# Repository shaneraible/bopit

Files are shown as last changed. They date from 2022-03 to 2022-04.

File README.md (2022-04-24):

# Disarm-It!
This project is based off the popular game Bop-It! 
In our version, we have three inputs:
- Scan it!
- Unlock it!
- Password it!

The software folder contains all of the arduino files, the pcb folder has all PCB files and the enclosure folder has all fusion360 files for the enclosure.

To achieve this, we created a PCB and 3D printed enclosure to go with the game. Enclosure design was done in Fusion360 and the PCB was design in Altium. 

# The PCB:
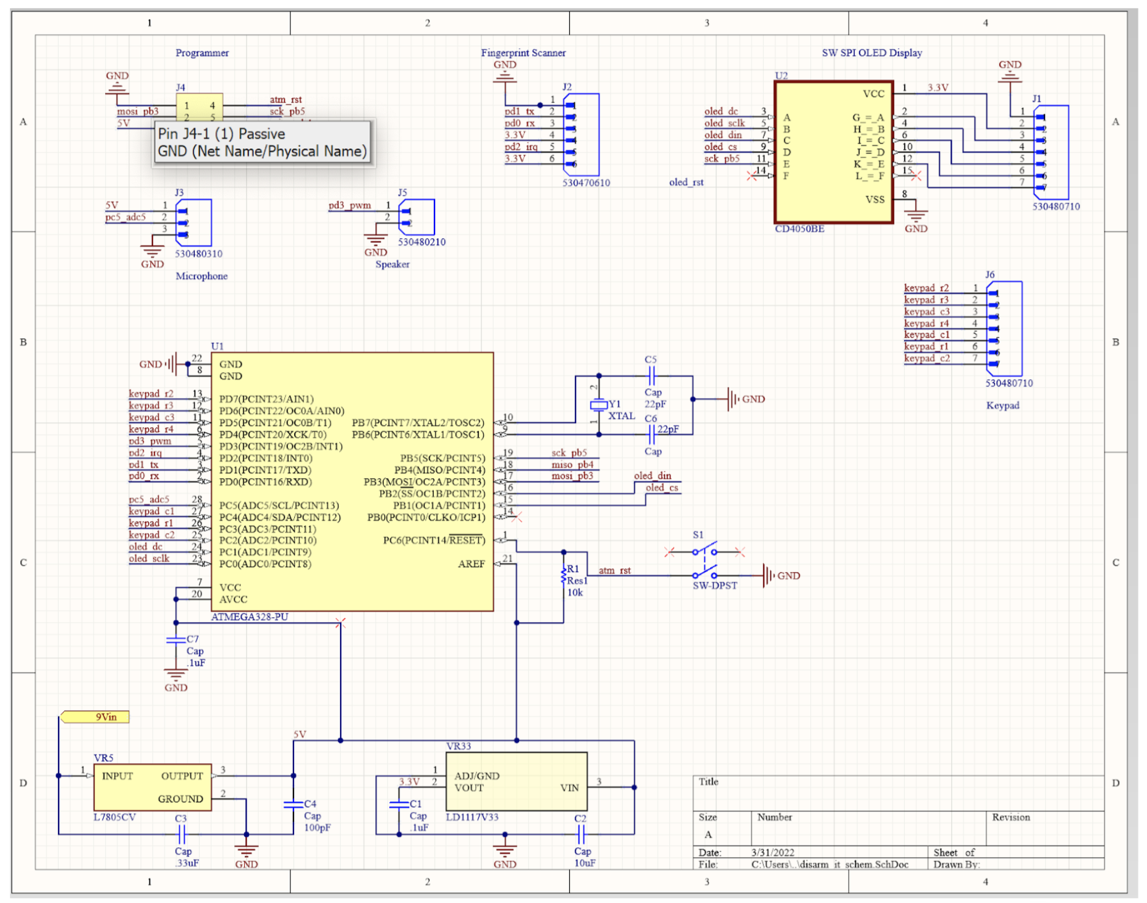
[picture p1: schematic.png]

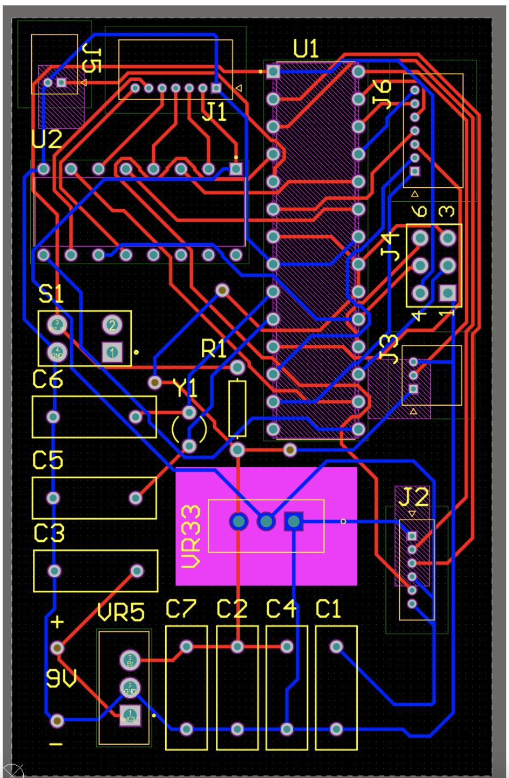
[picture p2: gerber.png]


# The enclosure:
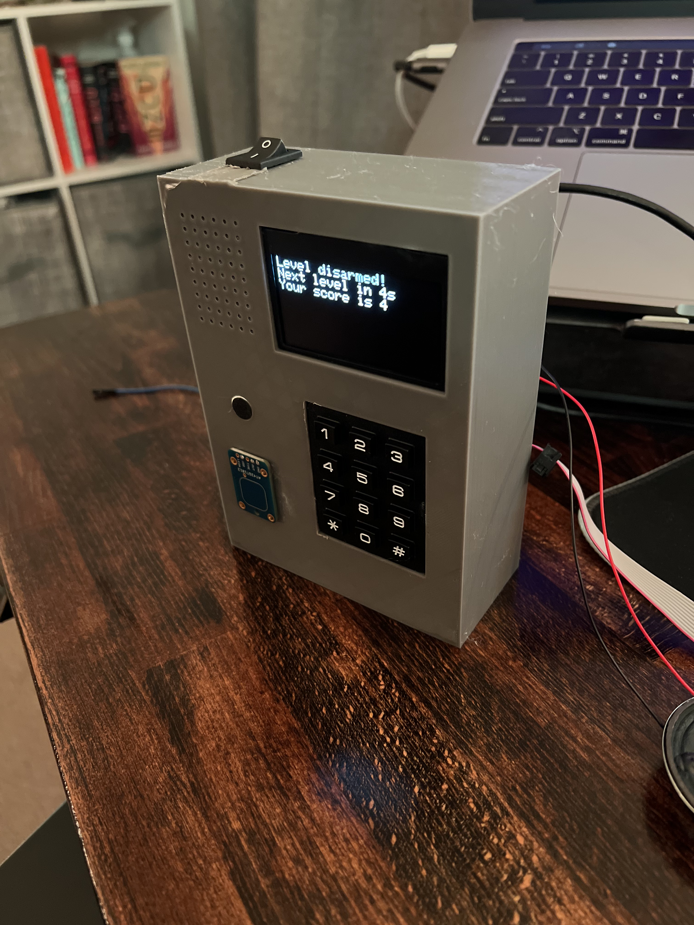
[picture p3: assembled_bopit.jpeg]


# Demo
https://www.youtube.com/watch?v=G1TUeg5arFM

# Contributers
Peri Hassanzadeh, Liam Neary, Shane Raible

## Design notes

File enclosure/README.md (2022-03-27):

# Enclosure

This Folder contains all files related to the enclosure's design, specifications, and manufacturing.

Primarily Managed by Liam

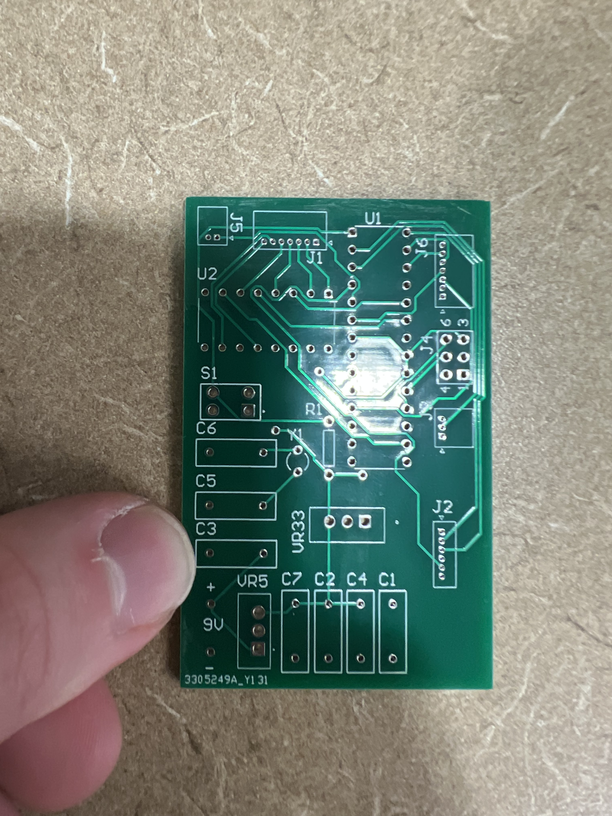
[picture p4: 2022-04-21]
PCB.jpeg

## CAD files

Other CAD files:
enclosure/bopit_design_v13.f3d

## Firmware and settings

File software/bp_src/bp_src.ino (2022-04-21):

///////////////////////////////////////////////
// DEFINITIONS FOR OLED DRIVER
///////////////////////////////////////////////
#include <Wire.h>
#include <SPI.h>
#include <Adafruit_GFX.h>
#include <Adafruit_SSD1305.h>

#define OLED_CLK A0
#define OLED_MOSI 10
#define SSD1305_128_64
#define OLED_CS 9
#define OLED_DC A1
#define OLED_RESET 13

#define NUMFLAKES 10
#define XPOS 0
#define YPOS 1
#define DELTAY 2

#define LOGO16_GLCD_HEIGHT 16 
#define LOGO16_GLCD_WIDTH  16 
static const unsigned char PROGMEM logo16_glcd_bmp[] =
{ B00000000, B11000000,
  B00000001, B11000000,
  B00000001, B11000000,
  B00000011, B11100000,
  B11110011, B11100000,
  B11111110, B11111000,
  B01111110, B11111111,
  B00110011, B10011111,
  B00011111, B11111100,
  B00001101, B01110000,
  B00011011, B10100000,
  B00111111, B11100000,
  B00111111, B11110000,
  B01111100, B11110000,
  B01110000, B01110000,
  B00000000, B00110000 };

void testdrawbitmap(const uint8_t *bitmap, uint8_t w, uint8_t h);

// Comment out if not using OLED
#define OLED
Adafruit_SSD1305 display(128, 64, OLED_MOSI, OLED_CLK, OLED_DC, OLED_RESET, OLED_CS);

/////////////////////////////////////
// Utilities: 
#ifdef OLED
#define DP_PRINTLN(x) display.println(F(x))  //use F(X) to save the string to Flash
#define DP_PRINT(x) display.print(F(x)) //use F(X) to save the string to Flash
#define DISPLAY() display.display()
#else
#define DP_PRINTLN(x) Serial.println(F(x))   //use F(X) to save the string to Flash
#define DP_PRINT(x) Serial.print(F(x))       //use F(X) to save the string to Flash
#define DISPLAY()
#endif

///////////////////////////////////////////////
// KEYPAD SENSOR
///////////////////////////////////////////////
//https://arduinogetstarted.com/tutorials/arduino-keypad
#include <Keypad.h>

const int ROW_NUM = 4; //four rows
const int COLUMN_NUM = 3; //three columns

char keys[ROW_NUM][COLUMN_NUM] = {
  {'1','2','3'},
  {'4','5','6'},
  {'7','8','9'},
  {'*','0','#'}
};

byte pin_rows[ROW_NUM] = {A3, 7, 6, 4}; //connect to the row pinouts of the keypad
byte pin_column[COLUMN_NUM] = {A4, A2, 5}; //connect to the column pinouts of the keypad

Keypad keypad = Keypad( makeKeymap(keys), pin_rows, pin_column, ROW_NUM, COLUMN_NUM );
String randompasscode();
String password = randompasscode(); // change your password here
String input_password = "FFFF";
bool getcode = false;

///////////////////////////////////
//        GAME SETTINGS          //
///////////////////////////////////
#define START_DELAY 2000
#define DELAY_STEP  100

#define FINGERPRINT_TONE 600
#define KEYPAD_TONE 200
#define unlock_TONE 400
#define TONE_DURATION 100
#define TONE_PIN 3

#define MAX_SCORE 10
#define START_DT 8000
#define MIN_DT 3000

///////////////////////////////////
//    STATES FOR STATE MACHINE   //
///////////////////////////////////

typedef void (*State) ();

void start_screen();
void handle_input();
void wait_and_select_input();
void game_over();
bool keypad_logic();

enum states {
  START_SCREEN,
  HANDLE_INPUT,
  WAIT_AND_SELECT_INPUT,
  GAME_OVER
};

#define NUM_INPUTS 3
enum inputs {
  FINGERPRINT_SCANNER,
  KEYPAD,
  MICROPHONE
};

State states[] = {start_screen, handle_input, wait_and_select_input, game_over};

inputs input      = (inputs)0;
int current_state = START_SCREEN;
int next_state    = 0;
int score         = 0;
bool over         = false;

long timeout      = 0;
int time_step     = START_DT;
int time_sub      = (START_DT-MIN_DT)/MAX_SCORE;
  

////////////////////////////////////
//          MICROPHONE            //
////////////////////////////////////
#define MIC_IN A5
#define BG_SCALE 1.2

bool get_unlock_input();
int background_sound = 0;
int prev_pos = 0;

////////////////////////////////////

////////////////////////////////////
//          TOUCH SENSOR          //
////////////////////////////////////
#define touchsensor 2
int current_touchstate = LOW;


void reset_display(){
  #ifdef OLED
  display.clearDisplay(); //use this to clear display

  //clear display resets all settings, configure text:
  display.setRotation(2);
  display.setTextSize(1);
  display.setTextColor(WHITE);
  display.setCursor(0,0); //cursor start in top left
  #endif
}

void setup() {
  #ifndef OLED
  Serial.begin(9600);
  while (! Serial) delay(100);
  #endif

  #ifdef OLED
  if ( ! display.begin(0x3C) ) {
     while (1) yield();
  }
  #endif

  reset_display();
  DISPLAY();
  
  current_touchstate = digitalRead(touchsensor);
  background_sound = BG_SCALE*analogRead(MIC_IN);
  
  input_password.reserve(32); // maximum input characters is 33, change if needed

  pinMode(touchsensor, INPUT);

}

void loop() {
  current_state = next_state;
  states[current_state]();
}


void start_screen() {
  reset_display();
  current_touchstate == digitalRead(touchsensor);
  background_sound = BG_SCALE*analogRead(MIC_IN);
  
  DP_PRINTLN("Disarm-it!");
  DP_PRINTLN("");
  DP_PRINTLN("Scan finger to start");
  DP_PRINTLN("");
  DP_PRINT("Your passcode is ");
  display.println(password);
  DISPLAY();

  while(current_touchstate == digitalRead(touchsensor)){};
  
  reset_display();
  for (uint8_t i=0; i<display.height()/2; i+=2) {
    display.drawRect(i, i, display.width()-2*i, display.height()-2*i, WHITE);
    display.display();
  }

  next_state = WAIT_AND_SELECT_INPUT;

}

void wait_and_select_input(){
  reset_display();
  current_touchstate == digitalRead(touchsensor);
  prev_pos = analogRead(MIC_IN);
  
  if(!over && score < MAX_SCORE){
    int i = input;
    input = rand()%NUM_INPUTS;

    if(input == i){
      input = rand()%NUM_INPUTS;
    }

    switch(input){
      case FINGERPRINT_SCANNER:
        DP_PRINTLN("Scan it!");
        tone(TONE_PIN, FINGERPRINT_TONE, TONE_DURATION);
        break;
      case KEYPAD:
        DP_PRINTLN("Password it!");
        tone(TONE_PIN, KEYPAD_TONE, TONE_DURATION);
        break;
      case MICROPHONE:
        DP_PRINTLN("Unlock it!");
        tone(TONE_PIN, unlock_TONE, TONE_DURATION);
        DISPLAY();
        delay(1500);
        break;
    }
    DISPLAY();

    timeout = millis() + time_step;
    next_state = HANDLE_INPUT;
  }
  else{
    next_state = GAME_OVER;
  }
}


void handle_input(){
  switch(input){
    case FINGERPRINT_SCANNER:
      over = fingerprint_scanner_input();
      break;
    case KEYPAD:
      over = keypad_logic();
      break;
    case MICROPHONE:
      over = get_unlock_input();
      break;
  } 

   if(!over) score++;
  if (!over && score<MAX_SCORE) tone(TONE_PIN, 1000, 500);
  //delay until next state
  while(score<MAX_SCORE && !over && millis() < timeout){
    reset_display();
    DP_PRINTLN("");
    DP_PRINTLN("Level disarmed!");
    DP_PRINT("Next level in ");
    current_touchstate = digitalRead(touchsensor);
    long s = (timeout - millis())/1000;
    display.print(s);
    DP_PRINTLN("s");
    DP_PRINT("Your score is ");
    display.println(score);
    DP_PRINT("You have ");
    display.print (time_step);
    DP_PRINTLN("ms next round");
    DISPLAY();
  }
  
  time_step = time_step - time_sub;


  next_state = WAIT_AND_SELECT_INPUT;
}

bool get_unlock_input(){

  DP_PRINTLN("Twist the key!");
  DISPLAY();
  
  bool g_over = true;
  int current = 0;
  
  delay(50);
  
  while(g_over && millis() < timeout){
    
    current = analogRead(MIC_IN);
    g_over = abs(current-prev_pos)<500 ;
  }
  return g_over;
}

void game_over(){
  if(score < MAX_SCORE){
    tone(TONE_PIN, 50, 1000);
    testdrawbitmap(logo16_glcd_bmp, LOGO16_GLCD_HEIGHT, LOGO16_GLCD_WIDTH);
    DP_PRINTLN("GAME OVER!");
    DP_PRINT("YOUR SCORE WAS: ");
  }
  else{
    tone(TONE_PIN, 500, 1000);
    testdrawbitmap(logo16_glcd_bmp, LOGO16_GLCD_HEIGHT, LOGO16_GLCD_WIDTH);
    DP_PRINTLN("Winner!");
    DP_PRINTLN("");
    DP_PRINT("Score: ");
    display.println(score);
  }
  
  display.print(score);
  DISPLAY();

  score = 0;
  over = false;

  delay(10000);
  current_touchstate = digitalRead(touchsensor);
  next_state = START_SCREEN;
  time_step = START_DT;
}

bool keypad_logic(){
  input_password = ""; // clear input password
  DP_PRINTLN("Enter password below:");
  DISPLAY();
  
  while(millis() < timeout){
    char key = keypad.getKey();
    if (key){
      display.print(key);

      if(key == '*') {
        input_password = ""; // clear input password
        reset_display();
        DP_PRINTLN("Enter password below:");
        DISPLAY();
      } else if(key == '#') {
        if(password == input_password) {
          DP_PRINTLN("");
          DP_PRINTLN("Correct!");
          DISPLAY();
          return false;
        } else {
          DP_PRINTLN("");
          DP_PRINT("You entered: ");
          display.println(input_password);
          DP_PRINTLN("password is incorrect, try again");
          DISPLAY();
        }
  
        input_password = ""; // clear input password
      } else {
        input_password += key; // append new character to input password string
      }
      DISPLAY();
    }
  }

  return true;
}

String randompasscode(){
  String pass = "";
  
  for(int i=0; i<4; i++)
  {
    int digit = (rand()%9)+1;
    String digitchar = String(digit);
    pass += digitchar;
  }

  return pass;
}

bool fingerprint_scanner_input(){
  current_touchstate = digitalRead(touchsensor);
  DP_PRINTLN("SCAN FINGER");
  DISPLAY();
  delay(50);
  while(millis() < timeout){
      if(current_touchstate != digitalRead(touchsensor))
      {
        current_touchstate = digitalRead(touchsensor);
        return false;
      }
  }

  return true;
}

void testdrawbitmap(const uint8_t *bitmap, uint8_t w, uint8_t h) {
  uint8_t icons[NUMFLAKES][3];
  randomSeed(666);     // whatever seed
 
  // initialize
  for (uint8_t f=0; f< NUMFLAKES; f++) {
    icons[f][XPOS] = random(display.width());
    icons[f][YPOS] = 0;
    icons[f][DELTAY] = random(5) + 1;
    
    Serial.print("x: ");
    Serial.print(icons[f][XPOS], DEC);
    Serial.print(" y: ");
    Serial.print(icons[f][YPOS], DEC);
    Serial.print(" dy: ");
    Serial.println(icons[f][DELTAY], DEC);
  }
  int count = 0;
  while (count<24) {
    // draw each icon
    for (uint8_t f=0; f< NUMFLAKES; f++) {
      display.drawBitmap(icons[f][XPOS], icons[f][YPOS], logo16_glcd_bmp, w, h, WHITE);
    }
    display.display();
    delay(20);
    
    // then erase it + move it
    for (uint8_t f=0; f< NUMFLAKES; f++) {
      display.drawBitmap(icons[f][XPOS], icons[f][YPOS],  logo16_glcd_bmp, w, h, BLACK);
      // move it
      icons[f][YPOS] += icons[f][DELTAY];
      // if its gone, reinit
      if (icons[f][YPOS] > display.height()) {
        icons[f][XPOS] = random(display.width());
        icons[f][YPOS] = 0;
        icons[f][DELTAY] = random(5) + 1;
      }
    }
    count++;
   }
}

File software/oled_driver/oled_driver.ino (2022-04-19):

#include <Talkie.h>
#include "Vocab_Soundbites.h"
#include <TalkieUtils.h>
#include <Vocab_US_Large.h>
#include <Vocab_Special.h>

///////////////////////////////////////////////
// DEFINITIONS FOR OLED DRIVER
///////////////////////////////////////////////
#include <Wire.h>
#include <SPI.h>
#include <Adafruit_GFX.h>
#include <Adafruit_SSD1305.h>

#define OLED_CLK A0 
#define OLED_MOSI 10
#define SSD1305_128_64
#define OLED_CS 9
#define OLED_DC A1
#define OLED_RESET 13

Adafruit_SSD1305 display(128, 64, OLED_MOSI, OLED_CLK, OLED_DC, OLED_RESET, OLED_CS);
///////////////////////////////////////////////
// FINGERPRINT SENSOR
///////////////////////////////////////////////

// Utilities: 

// define print functions for use w/ screen
#define DP_PRINTLN(x) display.println(F(x))   //use F(X) to save the string to Flash
#define DP_PRINT(x) display.print(F(x))       //use F(X) to save the string to Flash


Talkie voice;

void setup() {
  Serial.begin(9600);
  while (! Serial) delay(100);
  display.println("SSD1305 OLED test");

  display.setRotation(2);
  
  if ( ! display.begin(0x3C) ) {
     display.println("Unable to initialize OLED");
     while (1) yield();
  }

  // init done
  display.display(); // show splashscreen
  delay(4);
  display.clearDisplay();   // clears the screen and buffer

  tone(3, 400, 100);

}

void loop() {

  DP_PRINTLN("This is how you print a new line");
  display.display();  //call this to flash to the display
  delay(300);         //delay 300ms (clocck no good)
  DP_PRINTLN("another line");
  display.display();
  delay(300);

  display.clearDisplay(); //use this to clear display

  //clear display resets all settings, configure text:
  display.setTextSize(1);
  display.setTextColor(WHITE);
  display.setCursor(0,0); //cursor start in top left

}

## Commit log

2022-03-17 Added Fusion 360 file for exterior
    [ece1895_bopit_exterior.f3d]
2022-03-22 initial pcb commit
    [PCB_Project.PrjPcb, disarm_it_schem.SchDoc]
2022-03-24 moved enclosure f3d file to folder and added readme
    [ece1895_bopit_exterior.f3d]
2022-03-30 schematic v1 added
    [disarm_it_schem.SchDoc]
2022-03-30 oled driver v0
2022-03-30 add oled connections
    [disarm_it_schem.SchDoc]
2022-03-31 pcb - parts placed
    [disarm-_it.PcbDoc, disarm_it.PcbDoc, disarm_it.PrjPcb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]
2022-04-05 remove fingerprint for now
2022-04-07 Added updated exterior with power switch
    [bopit_deisgn_v9.f3d]
2022-04-07 removed old enclosure version
    [ece1895_bopit_exterior.f3d]
2022-04-19 touch sensor added
2022-04-20 updates to fingerprint scanner
2022-04-20 fingerprint scanner updates
2022-04-24 updated to most recent enclosure design file
    [bopit_deisgn_v9.f3d, bopit_design_v13.f3d]
2022-04-25 final pcb
    [disarm_it.GBL, disarm_it.GBO, disarm_it.GBS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]
